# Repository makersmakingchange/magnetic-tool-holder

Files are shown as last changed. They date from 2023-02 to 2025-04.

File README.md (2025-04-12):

# Magnetic Tool Holder
The Magnetic Tool Holder is intended to allow someone to place a mouthstick (or another tool) on the holder and then retrieve it whenever they need it again. The holder is designed to be mounted using an adjustable smartphone mount.

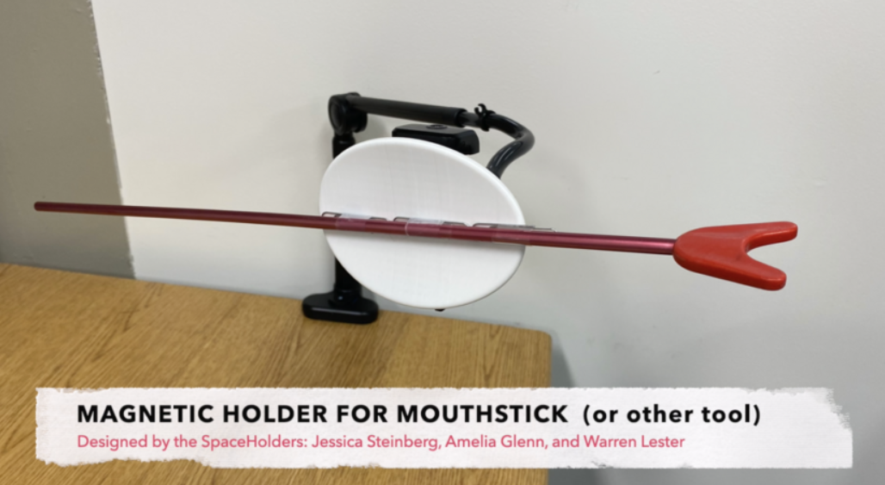
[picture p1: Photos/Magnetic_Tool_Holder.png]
Picture of Magnetic Tool Holder.


## More info at
- [Makers Making Change Project Page](https://makersmakingchange.com/project/magnetic-tool-holder/)

## How to Obtain a Magnetic Tool Holder
### 1. Do it Yourself (DIY) or Do it Together (DIT)

This is an open-source assistive technology, so anyone is free to build it. All of the files and instructions required to build the Magnetic Tool Holder are contained within this repository. Refer to the Maker Checklist below.

### 2. Request a build of this device

If you would like to obtain a Magnetic Tool Holder, you may submit a build request through the [MMC Library Page](https://makersmakingchange.com/project/magnetic-tool-holder/). The requestor is responsible for the cost of materials and any shipping.

### 3. How to build this device for someone else

If you have the skills and equipment to build this device, and would like to donate your time to create the switch for someone who needs it, visit the [MMC Maker Wanted](https://makersmakingchange.com/maker-wanted/) section.

## Getting Started

### 1. Read the Makers Checklist

The Makers Checklist provides an overview of all steps required to build the device.

### 2. Order the Off-The-Shelf Components

The [Bill of Materials](/Documentation/Magnetic_Tool_Holder_BOM_V1.0.xlsx) lists all of the parts and components required to build the Magnetic Tool Holder. The main switch component needs to be ordered online. The rest of the off-the-shelf components are also online or may be available in smaller quantities at your local hardware store or dollar store.

### 3. Print the 3D Printable components

All of the files and individual print files can be in the [/Build_Files/3D_Printing_Files](/Build_Files/3D_Printing_Files/) folder.

### 4. Assemble the Magnetic Tool Holder

Reference the [Assembly Guide](/Documentation/Magnetic_Tool_Holder_Assembly_Guide_V1.0.pdf) for the tools and steps required to build each portion.

## Files
### Documentation
| Document | Version | Link |
|---|---|---|
| Design Rationale | 1.0 | [Magnetic_Tool_Holder_Design_Rationale](/Documentation/Magnetic_Tool_Holder_Design_Rationale_V1.0.pdf) |
| Maker Checklist | 1.0 | [Magnetic_Tool_Holder_Maker_Checklist](/Documentation/Magnetic_Tool_Holder_Maker_Checklist_V1.0.pdf) |
| Bill of Materials | 1.0 | [Magnetic_Tool_Holder_Bill_of_Materials](/Documentation/Magnetic_Tool_Holder_BOM_V1.0.xlsx) |
| 3D Printing Guide | 1.0 | [Magnetic_Tool_Holder_3D_Printing_Guide](/Documentation/Magnetic_Tool_Holder_3D_Printing_Guide_V1.0.pdf) |
| Assembly Guide | 1.0 | [Magnetic_Tool_Holder_Assembly_Guide](/Documentation/Magnetic_Tool_Holder_Assembly_Guide_V1.0.pdf) |
| User Guide | 1.0 | [Magnetic_Tool_Holder_User_Guide](/Documentation/Magnetic_Tool_Holder_User_Guide_V1.0.pdf) |
| Changelog | 1.0 | [Magnetic_Tool_Holder_Changelog](/Documentation/Magnetic_Tool_Holder_Changelog_V1.0.pdf) |

### Design Files
 - [CAD Files](/Design_Files)

### Build Files
 - [3D Printing Files](/Build_Files/3D_Printing_Files)

## Attribution
Designers:
 - Designed by the SpaceHolders: Jessica Steinberg, Warren Lester, and Amelia Glenn 
 - Documentation by Neil Squire Society/Makers Making Change

## License
Everything needed or used to design, make, test, or prepare the Magnetic Tool Holder is licensed under the [Attribution-NonCommercial-ShareAlike 4.0 ](https://creativecommons.org/licenses/by-nc-sa/4.0/).

Accompanying material such as instruction manuals, videos, and other copyrightable works that are useful but not necessary to design, make, test, or prepare the <Device-Name> are published under a Creative Commons Attribution-ShareAlike 4.0 license https://creativecommons.org/licenses/by-sa/4.0/ (CC BY-SA 4.0).

---
<!-- ABOUT MMC START -->
## About Makers Making Change
[Makers Making Change Logo](https://www.makersmakingchange.com/)

Makers Making Change is a program of [Neil Squire](https://www.neilsquire.ca/), a Canadian non-profit that uses technology, knowledge, and passion to empower people with disabilities.

Makers Making Change leverages the capacity of community based Makers, Disability Professionals and Volunteers to develop and deliver affordable Open Source Assistive Technologies.

 - Website: [www.MakersMakingChange.com](https://www.makersmakingchange.com/)
 - GitHub: [makersmakingchange](https://github.com/makersmakingchange)
 - Bluesky: [@makersmakingchange.bsky.social](https://bsky.app/profile/makersmakingchange.bsky.social)
 - Instagram: [@makersmakingchange](https://www.instagram.com/makersmakingchange)
 - Facebook: [makersmakechange](https://www.facebook.com/makersmakechange)
 - LinkedIn: [Neil Squire Society](https://www.linkedin.com/company/neil-squire-society/)
 - Thingiverse: [makersmakingchange](https://www.thingiverse.com/makersmakingchange/about)
 - Printables: [MakersMakingChange](https://www.printables.com/@MakersMakingChange)

### Contact Us
For technical questions, to get involved, or to share your experience we encourage you to [visit our website](https://www.makersmakingchange.com/) or [contact us](https://www.makersmakingchange.com/s/contact).
<!-- ABOUT MMC END -->

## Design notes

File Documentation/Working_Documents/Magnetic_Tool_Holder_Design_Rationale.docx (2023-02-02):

# Introduction

This Magnetic Tool Holder is designed to allow someone to place a mouthstick (or another tool) on the holder and then retrieve it whenever they need it again.

The holder is designed such that most smartphone mounts can be used to mount it.

Magnets are inserted inside the holder, and then a couple small magnetic objects (bobby pins, paper clips, etc.) are attached to the mouthstick so it is attracted to the magnets.

Since the magnets are in a line and the holder is curved, the mouthstick snaps into place when it is placed close to the holder. This leaves it within easy reach to be retrieved for use.

# Requirements

## Goals

G01 | Magnetically hold tools in a convenient location

## Functional Requirements

F01 | Hold magnetic tools in place on the mounting surface
F02 | Have a low enough force that the tools can be removed with the user’s mouth
F03 | Be attached to a commercial phone mount

## Constraints

C01 | Using just 3D printed and off the shelf parts

# Opportunities for Improvement

The mounting system can be changed from using a phone mount to a more standard ¼-20 mounting system.

© 2023 by Neil Squire. This work is licensed under the CC BY SA 4.0 License: http://creativecommons.org/licenses/by-sa/4.0 Files available at https://makersmakingchange.com/project/magnetic-tool-holder/ Page 1 of 2

V1.0 | January 2023 Magnetic Tool Holder Design Rationale

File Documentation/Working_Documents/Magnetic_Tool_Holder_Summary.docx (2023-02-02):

# Title

Magnetic Tool Holder

## Subtitle

This Magnetic Tool Holder is designed to allow someone to place a mouthstick (or another magnetic tool) on the holder and then retrieve it whenever they need it again.

## Device Details

### Overview

This Magnetic Tool Holder is designed to allow someone to place a mouthstick (or another magnetic tool) on the holder and then retrieve it whenever they need it again.

The holder is designed such that most smartphone mounts can be used to mount it.

Magnets are inserted inside the holder, and then a couple small magnetic objects (bobby pins, paper clips, etc.) are attached to the mouthstick so it is attracted to the magnets.

Since the magnets are in a line and the holder is curved, the mouthstick snaps into place when it is placed close to the holder. This leaves it within easy reach to be retrieved for use.

### Build Instructions

1. View demo video: https://www.youtube.com/watch?v=OtmZyDHDPjM
2. Print Mouthstick Holder and Magnet Cover (see link to Thingiverse for files)
3. Remove supports
4. Insert magnets into the holder. Be careful that magnets are secured such that they do not fly towards each other and cause injury.
5. Slide magnet cover in the slot on the back of the holder
6. Mount holder on phone mount or similar mounting device

#### Time Required

3D Printing Time: 7h17min

Assembly Time: 5 min

#### Tools

- 3D Printer

#### Components

- 1X 3D Printed Mouthstick Holder v1.stl
- 1X 3D Printed Magnet Cover for Mouthstick Holder v1.stl
- 3X 12x4 mm neodymium magnets (12mm diameter, 4mm thickness) (e.g., Amazon Link (https://www.amazon.ca/Approximately-Multi-use-Refrigerator-Magnets-Projects/dp/B07CJK761T))
- Bobby pins/paper clips/small magnetic objects
- Tape

### Attribution

Designed by the SpaceHolders: Jessica Steinberg, Warren Lester, and Amelia Glenn

Documentation by Neil Squire Society/ Makers Making Change

© 2023 by Neil Squire. This work is licensed under the CC BY SA 4.0 License: http://creativecommons.org/licenses/by-sa/4.0 Files available at https://makersmakingchange.com/project/magnetic-tool-holder/ Page 1 of 2

V1.0 | January 2023 Magnetic Tool Holder Summary

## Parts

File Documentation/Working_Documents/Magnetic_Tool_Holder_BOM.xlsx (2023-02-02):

Device: Magnetic Tool Holder |  | Total Cost | Total Print time (hr) | Total filament (g)
Version: V1.0 | Date Created: 01/18/2023 | $4.27 | 7.28 | 51
Commercial Parts:
Part type (Electrical. Mechanical, Sanitization, ect) | Part Name | Quantity Needed | Pkg Quantity | Price per package | Price per Unit | Price for qty needed | Link
Mechanical | Neodynium Magnet | 3 | 15 | $14.99 | $1.00 | $3.00 | 15 Pieces 12 x 4mm [ 8/17 x 4/25 inch] Approximately Tiny Round Disc Small Multi-use Refrigerator Magnets for Refrigerator Science Crafts Projects : Amazon.ca: Home (https://www.amazon.ca/Approximately-Multi-use-Refrigerator-Magnets-Projects/dp/B07CJK761T)
Mechanical | Tape
Mechanical | Paperclip/Small magnetic object | Variable
3D Printed Parts ESTIMATED PRICING USING 1KG ROLL COST: | $25.00
Part | Description | Quantity Needed | TOTAL Mass (g) | Estimated Price | Print Time (Min) | Link
Mouthstick_Holder_v1 | Main body | 1 | 47 | $1.18 | 409
Magnet_Cover_for_Mouthstick_Holder_v1 | cover panel | 1 | 4 | $0.10 | 28
 |  |  |  | $0.00
 |  |  |  | $0.00
 |  |  |  | $0.00
 |  |  | Total Print Cost: | $1.28
Tools for Assembly
Alternatives (if there are other sources for some parts link them below)
Part and description | Link

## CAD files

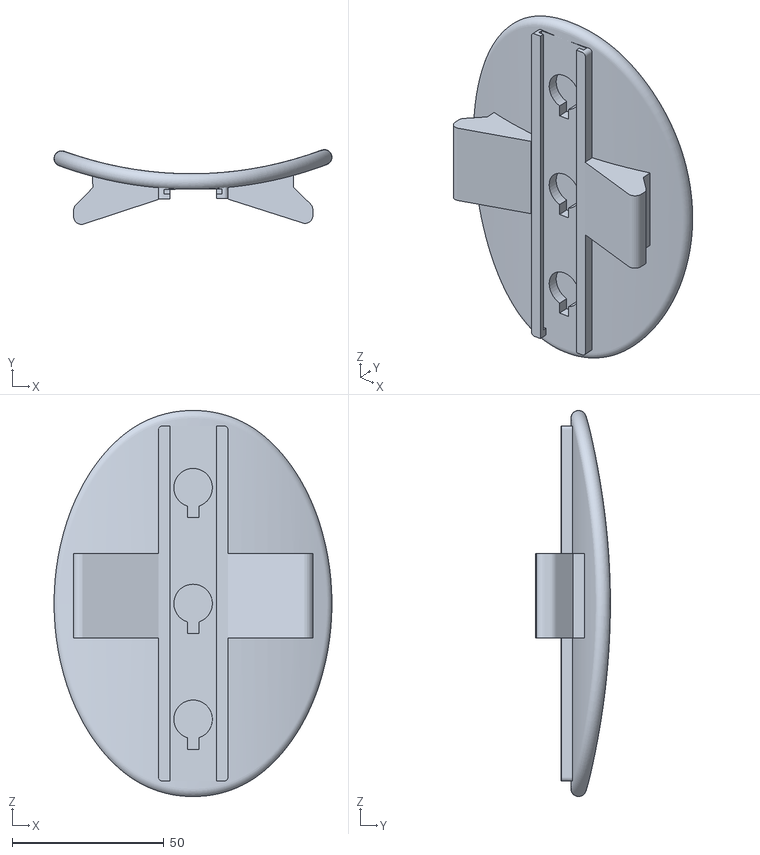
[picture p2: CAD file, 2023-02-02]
Build_Files/3D_Printing_Files/Mouthstick_Holder_v1.stl
91.4 x 24.6 x 127.0

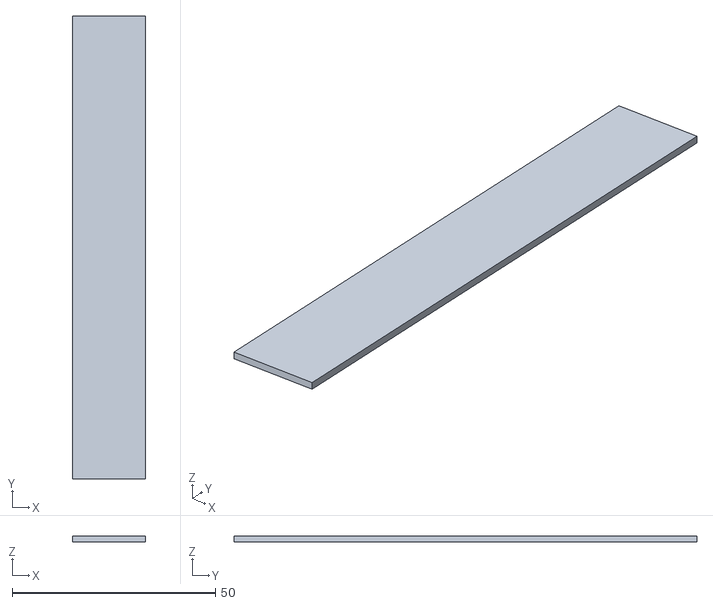
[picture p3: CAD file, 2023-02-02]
Build_Files/3D_Printing_Files/Magnet_Cover_for_Mouthstick_Holder_v1.stl
18.0 x 113.8 x 1.40

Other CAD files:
Design_Files/Mouthstick_Holder_v1.step
Design_Files/Magnet_Cover_for_Mouthstick_Holder_v1.step

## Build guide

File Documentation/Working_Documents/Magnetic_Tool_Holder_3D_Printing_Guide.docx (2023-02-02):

# 3D Printing Summary

Metrics
Total Print Time (hr:min) | 7:17
Total Number of Components | 2
Typical Total Mass (g) | 51
Typical Number of Print Setups | 2

# 3D Printing Settings

Print File Name | Qty | Total Print Time (hr:min) | Mass (g) | Infill (%) | Support (Y/N) | Layer Height/ Nozzle Diameter(mm) | Notes (orientation, special settings, etc.)
Mouthpiece_Holder_v1.stl | 1 | 6:49 | 47 | 20 | Y | 0.2/0.4 | - Print in orientation given in STL
Magnet_Cover_for_ Mouthstick_Holder_v1 | 1 | 0:28 | 4 | 20 | N | 0.2/0.4 | - Print in orientation given in STL

# Customization Options

- The device can be printed in any colour the user would like

# Post-Processing

- Remove all supports
- Remove sharp edges with a hobby knife and sandpaper

# Examples of Quality Prints

Photos of Mouthpiece_Holder_v1

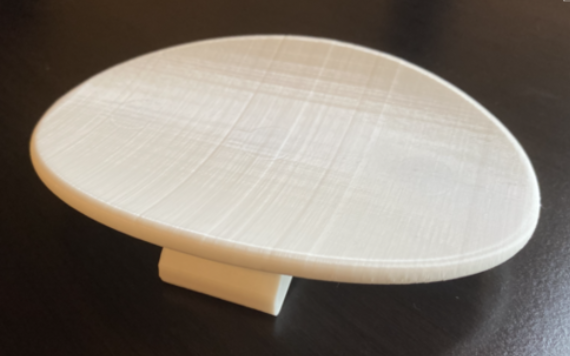
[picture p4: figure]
Top view of Mouthpiece Holder
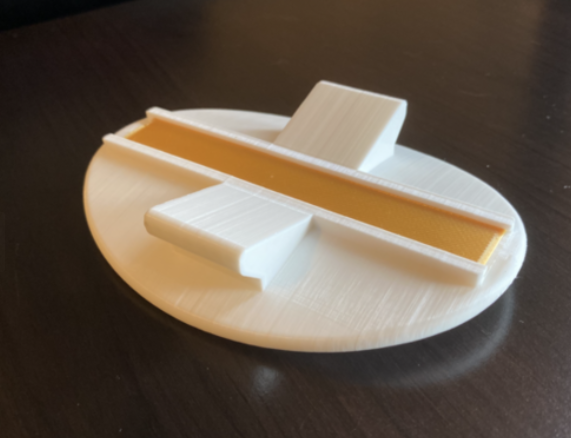
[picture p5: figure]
Bottom view of Mouthpiece holder

Photos of Magnet_Cover_for_Mouthstick_Holder_v1

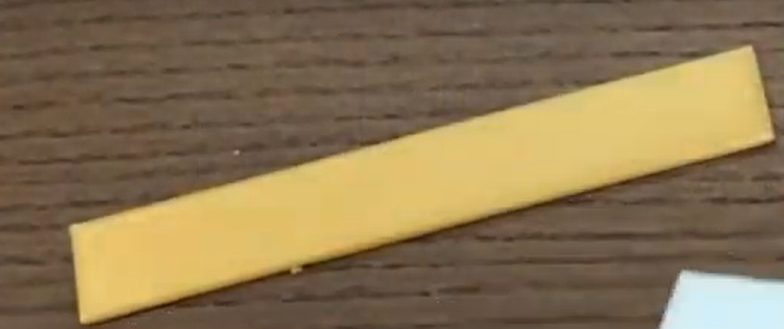
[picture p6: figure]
Picture of Magnet cover for mouthstick holder

© 2023 by Neil Squire Society. This work is licensed under the CC BY SA 4.0 License: http://creativecommons.org/licenses/by-sa/4.0 Files available at https://makersmakingchange.com/project/magnetic-tool-holder/ Page 1 of 2

V1.0 | January 2023 Magnetic Tool Holder 3D Printing Guide

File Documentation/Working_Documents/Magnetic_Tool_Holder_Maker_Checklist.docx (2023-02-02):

# Maker To Do List

- Read through the Assembly Guide to become familiar with required components, tools, supplies, and safety gear and overall assembly steps.
- Talk to User about customization options (e.g., color, any special requests, etc.)
- Order hardware components
- Gather tools, supplies, and safety equipment.
- Assemble the device
- Test device
- Print “User Quick Guide”

# Items to Give to User

- Assembled, tested device
- “User Quick Guide”

© 2023 by Neil Squire. This work is licensed under the CC BY SA 4.0 License: http://creativecommons.org/licenses/by-sa/4.0 Files available at https://makersmakingchange.com/project/magnetic-tool-holder/ Page 1 of 1

V1.0 | January 2023 Magnetic Tool Holder Maker Checklist

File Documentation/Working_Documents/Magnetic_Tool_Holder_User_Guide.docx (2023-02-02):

## Introduction

This magnetic tool holder is designed to allow someone to place a mouthstick (or another tool) on the holder and then retrieve it whenever they need it again.

## Features

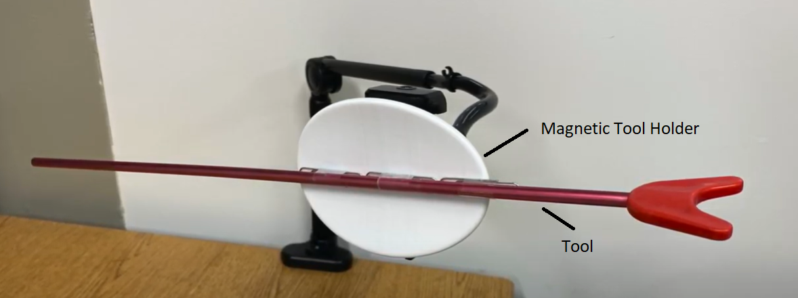
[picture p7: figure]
Front view of assembled device
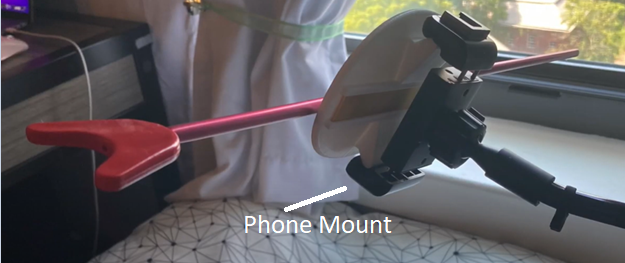
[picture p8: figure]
rear view of assembled device

## Usage

To use, insert three neodymium magnets in the slots on the back of the tool holder and cover them with the magnet cover. Insert the tool holder in a phone mount. At this point, any magnetic item under the weight of a pair of scissors can be placed against the holder and have it stay in place.

Paperclips or other small magnetic items can be attached to non-magnetic items to the holder.

## Compatibility

This toolholder will hold any magnetic item under the weight of a pair of scissors, and is mounted on a standard phone holder.

## Cleaning

The device can be wiped clean with a damp cloth.

© 2023 by Neil Squire. This work is licensed under the CC BY SA 4.0 License: http://creativecommons.org/licenses/by-sa/4.0 Files available at https://makersmakingchange.com/project/magnetic-tool-holder/ Page 1 of 2

V1.0 | January 2023 Magnetic Tool Holder user Quick Guide

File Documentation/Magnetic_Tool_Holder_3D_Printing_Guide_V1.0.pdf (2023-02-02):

V1.0 | January 2023

# Magnetic Tool Holder

# 3D PRINTING GUIDE

© 2023 by Neil Squire Society. This work is licensed under the CC BY SA 4.0 License: http://creativecommons.org/licenses/by-sa/4.0
Files available at https://makersmakingchange.com/project/magnetic-tool-holder/ | Page 1 of 3

# 3D Printing Summary

## Metrics

Total Print Time (hr:min) | 7:17
Total Number of Components | 2
Typical Total Mass (g) | 51
Typical Number of Print Setups | 2

# 3D Printing Settings

Print File Name | Qty | Total Print Time (hr:min) | Mass (g) | Infill (%) | Support (Y/N) | Layer Height/ Nozzle Diameter(mm) | Notes (orientation, special settings, etc.)
Mouthpiece_Holder_v1.stl | 1 | 6:49 | 47 | 20 | Y | 0.2/0.4 | -Print in orientation given in STL
Magnet_Cover_for_ Mouthstick_Holder_v1 | 1 | 0:28 | 4 | 20 | N | 0.2/0.4 | -Print in orientation given in STL

# Customization Options

## - The device can be printed in any colour the user would like

# Post-Processing

## - Remove all supports - Remove sharp edges with a hobby knife and sandpaper

# 3D PRINTING GUIDE

# Examples of Quality Prints

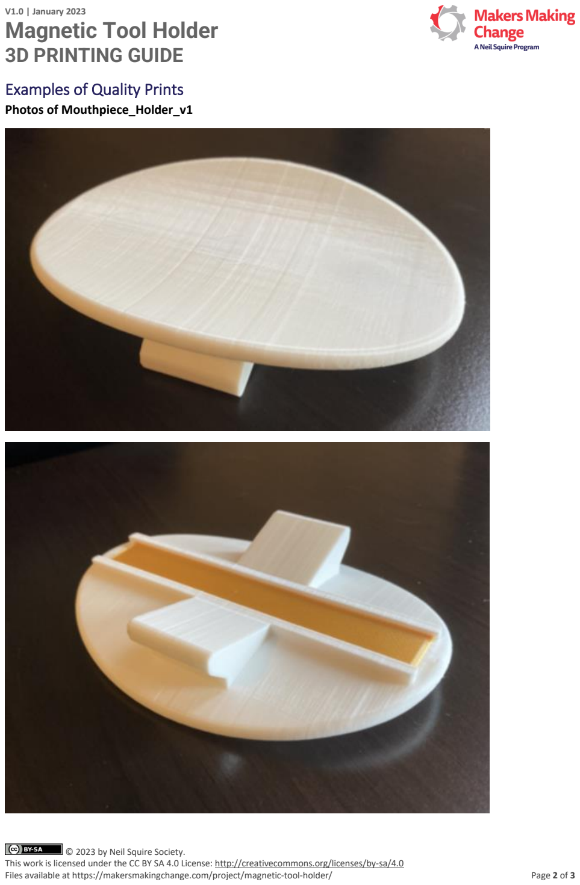
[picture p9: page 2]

Files available at https://makersmakingchange.com/project/magnetic-tool-holder/ | Page 2 of 3

## Photos of Mouthpiece_Holder_v1

# 3D PRINTING GUIDE

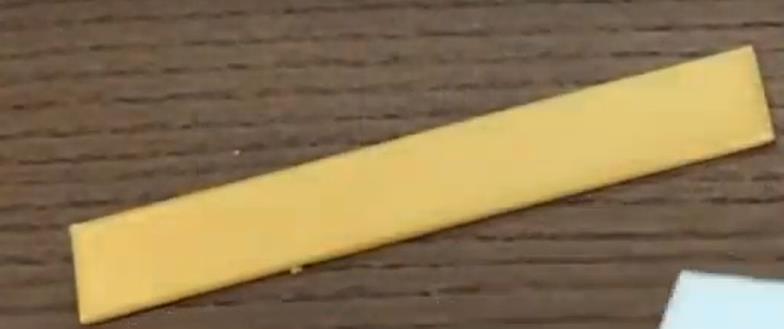
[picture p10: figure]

Files available at https://makersmakingchange.com/project/magnetic-tool-holder/ | Page 3 of 3

## Photos of Magnet_Cover_for_Mouthstick_Holder_v1

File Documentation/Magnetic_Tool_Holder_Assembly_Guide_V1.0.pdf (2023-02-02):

V1.0 | January 2023

# Magnetic Tool Holder

# ASSEMBLY GUIDE

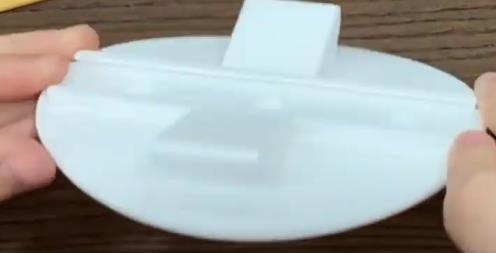
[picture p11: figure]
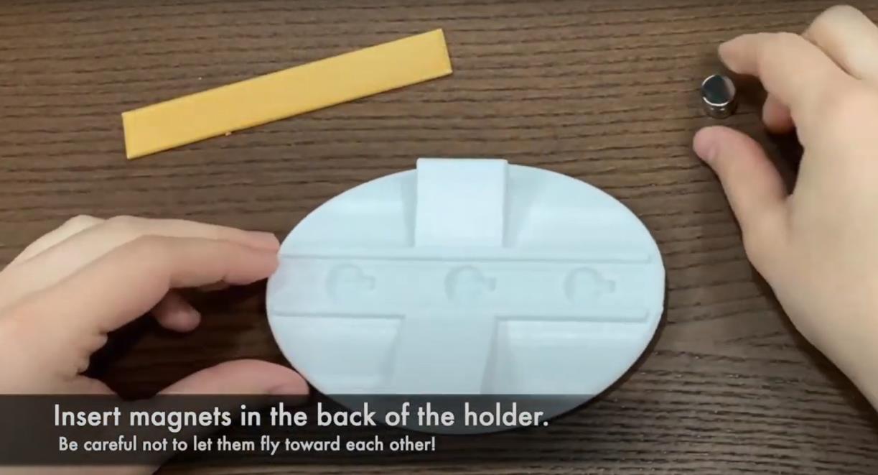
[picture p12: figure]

© 2023 by Neil Squire. (https://neilsquire.ca/)

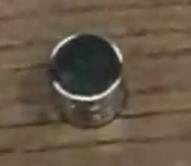
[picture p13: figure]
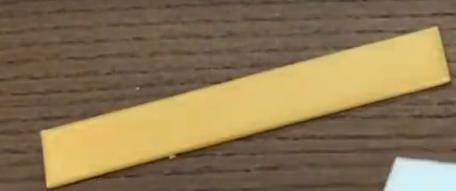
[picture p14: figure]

This work is licensed under the CC BY SA 4.0 License: http://creativecommons.org/licenses/by-sa/4.0
Files available at https://makersmakingchange.com/project/magnetic-tool-holder/ | Page 1 of 2

# Required Components

## BOM

1x Mouthpiece Holder | 3x Neodymium magnets

## 1x Magnet cover

# Assembly Instructions

## Step 1

Insert magnets in the back of the holder.

# Magnetic Tool Holder

# ASSEMBLY GUIDE

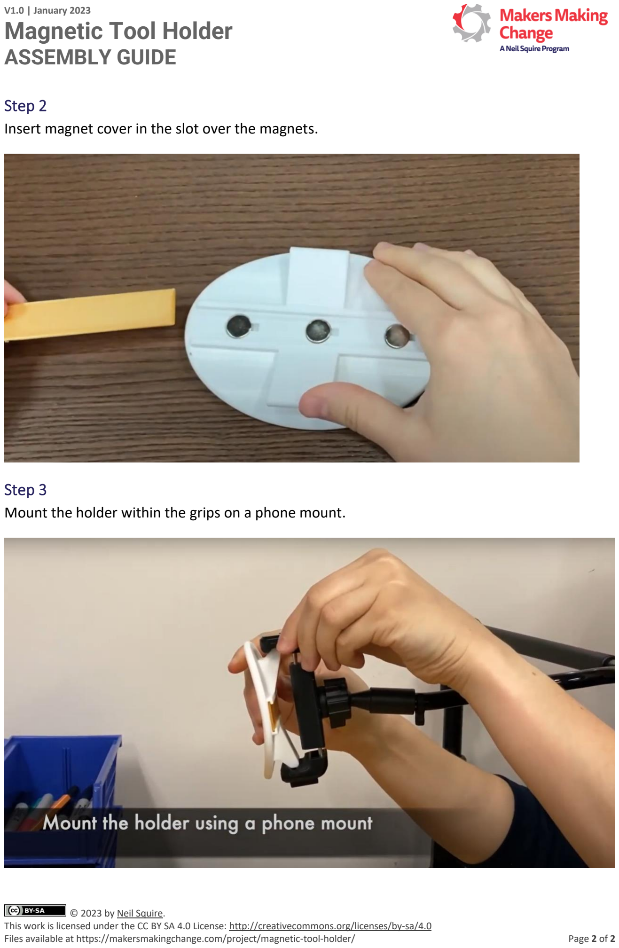
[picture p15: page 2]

V1.0 | January 2023

© 2023 by Neil Squire. (https://neilsquire.ca/)
This work is licensed under the CC BY SA 4.0 License: http://creativecommons.org/licenses/by-sa/4.0
Files available at https://makersmakingchange.com/project/magnetic-tool-holder/ | Page 2 of 2

## Step 2

Insert magnet cover in the slot over the magnets.

## Step 3

Mount the holder within the grips on a phone mount.

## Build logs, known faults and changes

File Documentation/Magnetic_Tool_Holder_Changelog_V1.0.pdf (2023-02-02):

V1.0 | January 2023

# Magnetic Tool Holder

# CHANGELOG

© 2023 by Neil Squire. (https://neilsquire.ca/)
This work is licensed under the CC BY SA 4.0 License: http://creativecommons.org/licenses/by-sa/4.0
Files available at https://makersmakingchange.com/project/magnetic-tool-holder/ | Page 1 of 1

# Version 1.0 | 2023/01/17

## - Designed by the SpaceHolders: Jessica Steinberg, Warren Lester, and Amelia Glenn - Documentation by Neil Squire Society/Makers Making Change
